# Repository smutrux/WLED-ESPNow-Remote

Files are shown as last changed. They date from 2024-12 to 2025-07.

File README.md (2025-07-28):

# WLED-ESPNow-Remote
ESPNow based remote controller for WLED using an ESP32-C3 with support for buttons, button matrix and rotary encoder. The code is Arduino based for easy compilation: developed and tested with Arduino IDE version 2.3.4

Hardware setup and button settings can be easily configured in the source code.

## Features
- Support for up to 6 standard button inputs (more when not using deep-sleep)
- Support for up to 36 buttons when using a 6x6 button matrix
- Support for rotary encoder input with configurable number of levels (see below)
- Each button can be assigned up to 3 functions: single click, double click and long press with automatic repeat
- Makes use of the low-power capabilities for battery powered remote controllers

## Supported hardware
- Controller: ESP32 C3
- Buttons: any button or sensor that has an active-low signal i.e. pulls to GND, external pullups are optional
- Button Matrix: any button matrix with row and column outputs with up to 6 rows and 6 columns, no external resistors or diodes required
- Rotary encoder: standard rotary encoders are supported, 1M external pullups are recommended for battery powered remotes

## Hardware setup
It is recommended to use the suggested pins given in the code. GPIO9 (boot pin) can generally not be used. For normal buttons, use GPIO0 through GPIO5. Any higher numbered GPIOs do not have wake-up capabilities and are only responsive when not in deep-sleep.

You can use the `ESP32_ESPNow_receiver.ino` in the `tools` folder running on a second ESP32 (should work on any ESP32 flavour) and open the serial monitor to check for received button codes. As an alternative: using a WLED device with debug output enabled will also display received messages on the serial output. 

### Standard Buttons
Connect each button between the GPIO and GND. External pull-up resistors are not needed but can be used, it makes no difference to functionality.

If more than 6 buttons are needed there are several options:
- use a matrix button configuration
- disable deep-sleep (`#DISABLE_DEEPSLEEP` in `config.h`) and any GPIO can be used (even GPIO9 although not recommended) at the expense of about **8 fold increased power consumption** (0.35mA vs. 0.04mA)
- use a button connected to GPIO0-GPIO5 to wake from deep sleep: during `ACTIVE_TIME` (see `config.h`) all configured GPIOs are responsive. Adjust `ACTIVE_TIME`  to your requriements

### Button Matrix
Connect the column-pins to GPIO0-GPIO5 as they are used as the inputs and need to be able to awaken the controller from deep-sleep. Connect the row-pins to any GPIO **except GPIO9**. Avoid pins with LEDs connected to them (GPIO8 on the C3 supermini for example) as it leads to (much) increased standby power consumption. 

The code is already set-up for a 4x4 button matrix, use the pins recommended in the code if possible. 

The button numbering is done from left to right, top to bottom with column 0 being on the left and row 0 being the top row. 

### Rotary Encoder
The CLK and DT pins of the encoder should be connected to GPIO0 and GPIO1. GPIO3, 4 and 5 can also be used, avoid any GPIOs with on-board pullups (i.e. GPIO2). 

For the button pin the use of GPIO2 is recommended although any GPIO from GPIO0 to GPIO5 can be used.

When using a rotary encoder module, connect GND to GND of the ESP and + to 3.3V of the ESP.

Additional buttons can be connected if required, the same restrictions mentioned above apply.

#### Tips for longer battery life using a rotary encoder
Standard rotary encoders have two resting postions: both (DT and CLK) pins floating and both pins connected to GND. To detect signals in deep-sleep an external pullup resistor is required. 
When using rotary encoder modules, these resistors are already in place, however, they consume a lot of power: when the two pins are in GND state, the pullup resistor of usually 10k resulting in deep-sleep curren of 700uA vs. ~45uA (see below). 

One way to get around this is to replace the resistors with higher value ones: 1M resistors work well, values larger than 3M are too weak to pull the pins to a reliable voltage. On the DT pin, an external resistor is not required and can be omitted.
Using 1M pull-up resistor only adds ~3uA per resistor to the deep-sleep current.

If you have no such resistors available, removing/omitting any pull-up resistors and enabling the `ENABLE_DEEPSLEEP_PULL` option is also possible, the internal pull-up resistors have a value of ~50k. Since only the pull-up on the CLK pin is enabled in deep-sleep,
the resulting current will be about 100uA. 

## Configuring and uploading the code
The default configuration uses 6 standard button inputs on GPIO0 - GPIO5. You can use this default configuration even when using less than 6 buttons: unused button pins will simple be idle and have no influence on power consumption. 

To upload the code, use the Arduino IDE (version 2.3.4 tested, newer version may or may not work)

Since the program puts the ESP in sleep mode, upload only works in bootloader mode: disconnect from USB, press and hold the boot button on the ESP32 C3, connect to USB then release the button and upload the code. Press reset after uploading to exit the bootloader.

By default, the on-board LED (GPIO8) will blink when data is sent out. If you see no blinking when pressing a button, there is something wrong with your hardware setup or the code was not uploaded properly. As mentioned above you can use the provided receiver sketch to for testing. 

### Changing the configuration
To change the hardware configuration, adjust the code in `config.h` according to your setup: comments in that file hopefully make it clear what each config parameter is used for.

The function numbers assigned to each button can be changed in the buttons.ino file where I added some examples. WLED supports the standard WiZ-mote codes by default, however those are highly limited in use. 
You can add a `remote.json` file to WLED using a web-browser (wled-ip/edit) to assign any supported JSON-API command to any button function. 

Triggering a preset using the command `{"ps":5}` to trigger preset 5 for example and adding the JSON-commands in the WLED web UI allows for easier adjustments than editing the remote.json file as that requires an active internet connection for the editor.

Example remote.json files are provided in the remote-json folder.

For details about the JSON-API please see [the documentation](https://kno.wled.ge)

## WLED setup
On your WLED controller you need to enable the ESPNow support and pair the remote in config->WiFi Setup, see https://kno.wled.ge/interfaces/infrared/#esp-now-based-remote-control

## How it all works
ESPNow is a wifi frequency based protocol by Espressif that works without an active wifi connection. This allows for low power communication as devices can quickly send messages without having to go 
through the wifi authentification process. The ESPNow remote code broadcasts a small message across all wifi channels (1-13) so it can be picked up by any WLED controller, no matter on what
channel it is currently on. This also works if the WLED controller is not connected to any wifi i.e. in AP mode. 

Since the messages are "blindly" broadcast there is no acknowledgement sent by the receiving controller. The remote therefore does not know if a message was received, all it knows if the message was sent: if there is heavy traffic
on the wifi channel used it can lead to messages being lost: the remote detects message collisions with normal wifi traffic and will try to send the message again but there is no guarantee that it will go through.
This can lead to messages sometimes being lost. If there is heavy traffic in your network and a lot of messages get lost, try increasing the `REPEATSEND` parameter or change the channel.

### Rotary encoder 
Standard rotary encoders allow to detect the rotation direction and trigger a message send out for each detent. To be able to control more settings, the "level" can be changed with a double-click on the encoder button.
The codes sent out for rotation are (counter clockwise / clockwise):

- level 0: WIZMOTE_BUTTON_BRIGHT_DOWN = 8 / WIZMOTE_BUTTON_BRIGHT_UP = 9
- level 1: WIZMOTE_BUTTON_ONE = 16 	  / WIZMOTE_BUTTON_ONE+1 = 17
- level 2: WIZMOTE_BUTTON_ONE+2 = 18 	  / WIZMOTE_BUTTON_ONE+3 = 19

(higher levels continue the same way)

- WIZMOTE_BUTTON_ONE+1 is also WIZMOTE_BUTTON_TWO
- WIZMOTE_BUTTON_ONE+2 is also WIZMOTE_BUTTON_THREE
- WIZMOTE_BUTTON_ONE+3 is also WIZMOTE_BUTTON_FOUR

these have default actions defined in WLED if no remote.json file is found

after some idle time (KEEPROTARYLEVEL_TIME) the level will be reset to 0 so that if you pick-up the remote after some time, it is set to the default of controlling brightness.

## Battery operation
The remote controller code was written and optimized for battery operated devices using a ESP32 C3 supermini. These controllers work down to ~3.6V input voltage on the 5V pin and are therefore perfectly suited for lithium polymer batteries. 
When the power LED is removed (see below) these controllers use only ~45uA (micro amperes or 0.045mA) when put into deep-sleep allowing for a very long battery life: a small 500mAh battery will last over a year without recharge.

Only use batteries with built-in protection circuits or use an external battery protection module for safety. It is also recommended to connect the battery through a charger module so it can be easily recharged.

Connect the battery power to the 5V and GND pin of the ESP board, using an external 3.3V regulator and using the 3.3V pin is not recommended as it increases power consumption unless the LDO on the ESP is removed. 

A key-press and the following sendout use about the same amount of enery as the remote uses in 2 minutes of deep-sleep, assuming the modifications mentioned i.e. removing the power LED. 
So unless a button is pressed more than 700 times per day, the deep-sleep power consumption is the dominating factor: hence the importance of low deep-sleep current. 

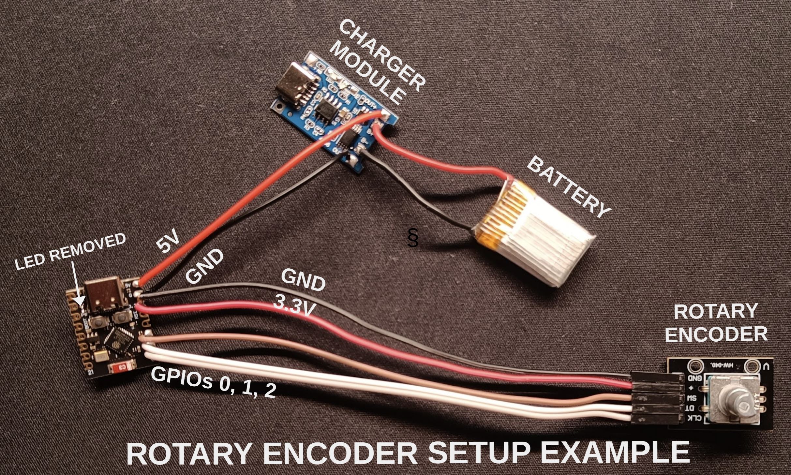
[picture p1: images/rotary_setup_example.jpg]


### Controller modifications for low power
The power-LED on the controller uses "a lot" of current, around 1mA and it is the dominating factor for battery life. It has to be removed to achieve the proclaimed ~45uA. The best (but not easiest) way to do this is to desolder it. 
It can also be cut/destroyed using pointy side-cutters or a knife, however there is the risk of damaging other components when not being careful. The small black resistor just next to the LED can also be removed as it is only used for the LED.

For more reliable operation add a 4.7uF or larger ceramic capacitor between the 3.3V pin and GND: I use 0805 sized 10uF/25V capacitors soldered directly to the C3 supermini pads. The capacitor helps to store energy required for the send-bursts.

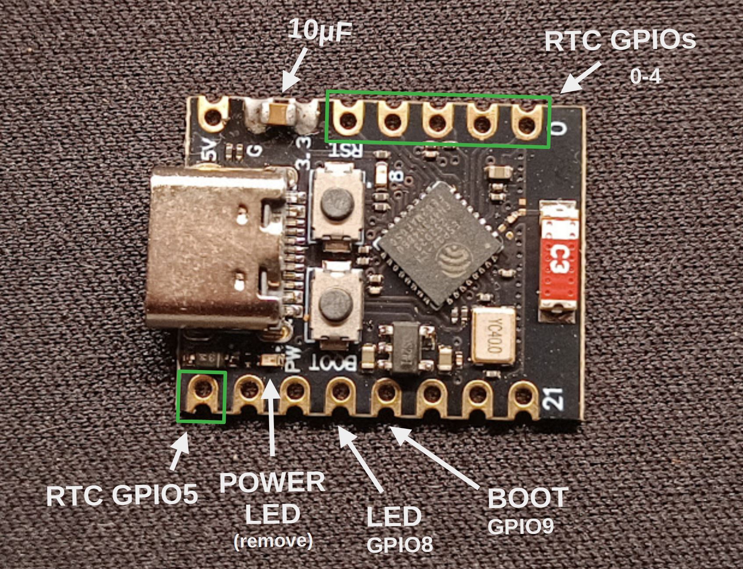
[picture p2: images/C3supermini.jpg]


### Note on ESP32 C3 Supermini variants
There are several variations of the C3 supermini, at least one of them is know to cause issues with the wifi-reception due to bad hardware design. The badly designe ones are easy to spot if you know what exactly to look for.
Here is a side-by-side comparison of the good and the bad.

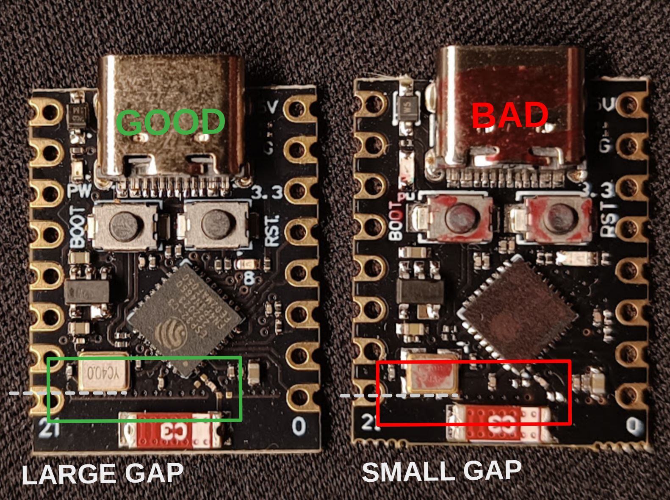
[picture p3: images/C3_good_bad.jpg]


I only own one of the bad ones and mine still works ok, the signal strength is reduced by about 50%. 

## Finished remote
PXL_20250728_000420064 RAW-01 MP COVER
PXL_20250728_000413364 RAW-01 MP COVER
PXL_20250728_000352728 RAW-01 MP COVER
PXL_20250728_000436622 RAW-01 MP COVER
PXL_20250728_000428658 RAW-01 MP COVER

## Examples for button modules
During development and testing I tried several different button-module designs that are commonly available in internet shops. Here are some fotos of tested and working configurations and which GPIOs are best to be used.

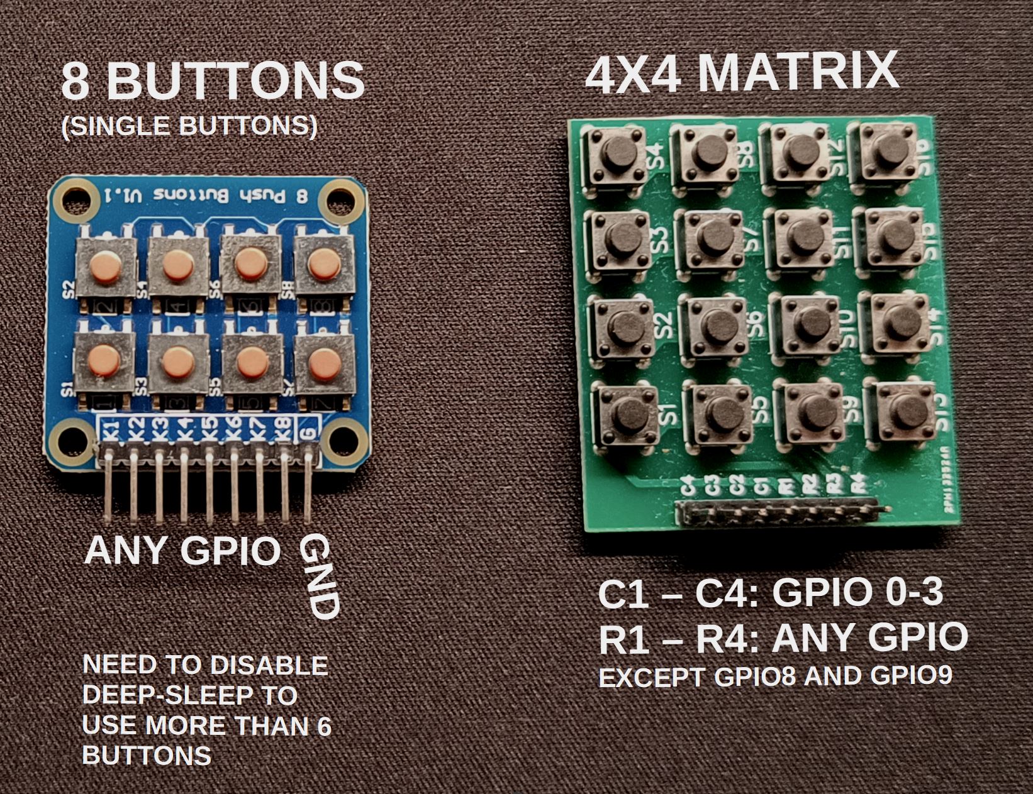
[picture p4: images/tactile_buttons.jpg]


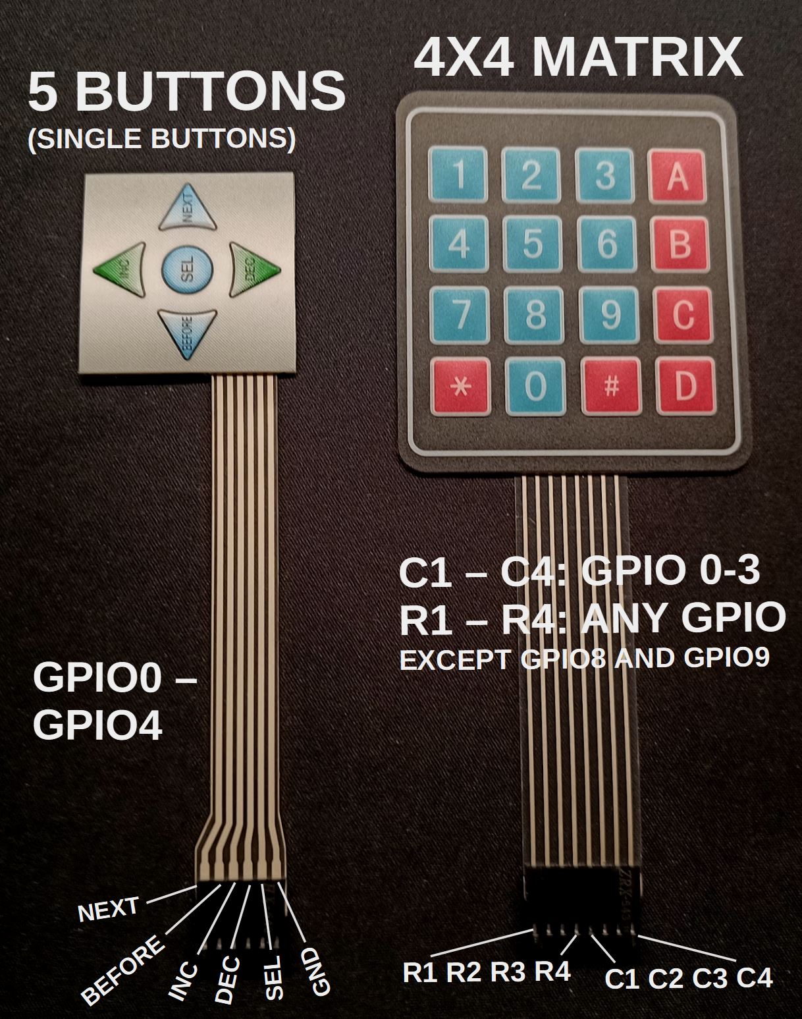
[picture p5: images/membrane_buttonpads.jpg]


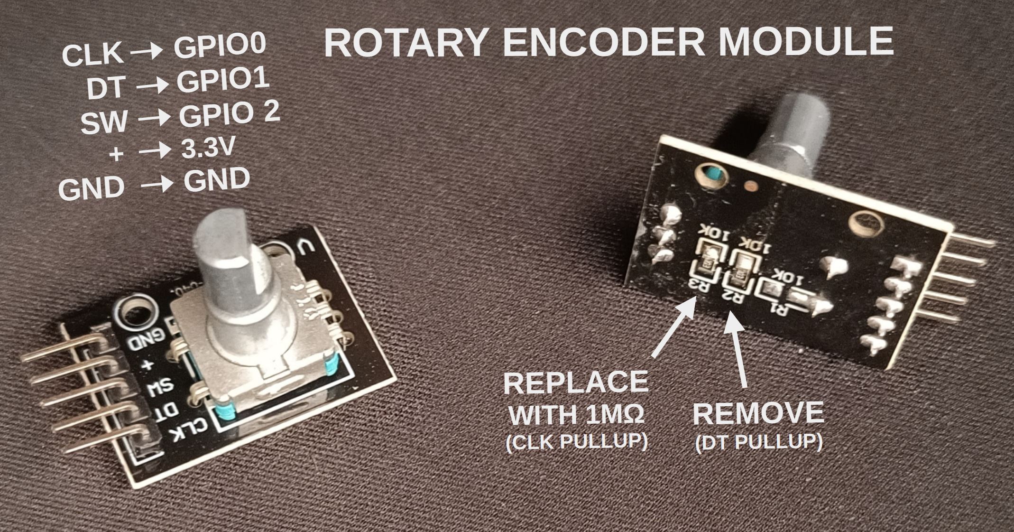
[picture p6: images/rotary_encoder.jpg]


## License and Credits

Licensed under the EUPL v1.2 license  
Code written and maintained by @DedeHai

*Disclaimer:*   

As per the EUPL license, I assume no liability for any damage to you or any other person or equipment.

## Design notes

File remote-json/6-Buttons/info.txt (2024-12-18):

Example remote.json for 6 buttons:

button0 single click: preset 1
button0 double click: preset 2
button0 long  press: preset 3

button1 single click: preset 4
button1 double click: preset 5
button1 long  press: preset 6

etc.

set DEFAULTS_START in buttons.ino to 0 and all buttons will use the default functions used in this example.
The default starts at button function number 16.
The example commands simply trigger a different preset for each button function.

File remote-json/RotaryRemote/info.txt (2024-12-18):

Example remote.json for remote with rotary encoder:

button single click: on
button double click: change level (no action sent)
button long  press: off

rotary level0 clockwise: increase brightness
rotary level0 counter-clockwise: decrease brightness

rotary level1 clockwise: next preset (presets 1 to 15)
rotary level1 counter-clockwise: previous preset (preset 1 to 15)

rotary level2 clockwise: next palette
rotary level2 counter-clockwise: previous palette

in buttons.ino:
set DEFAULTS_START to 1

use this configuration for the button:

buttons[0].singleClickFunction = WIZMOTE_BUTTON_ON; // = code 1
buttons[0].doubleClickFunction = 0;  // used to change rotary level
buttons[0].longPressFunction = WIZMOTE_BUTTON_OFF;  // = code 2
 
set NUM_ROTARYLEVELS to 3

Turning the rotary encoder will send these codes for different levels: coutnerclockwise / clockwise
- level 0: WIZMOTE_BUTTON_BRIGHT_DOWN = 8 / WIZMOTE_BUTTON_BRIGHT_UP = 9
- level 1: WIZMOTE_BUTTON_ONE = 16 	  / WIZMOTE_BUTTON_ONE+1 = 17
- level 2: WIZMOTE_BUTTON_ONE+2 = 18 	  / WIZMOTE_BUTTON_ONE+3 = 19

(higher levels continue the same way)

note:
WIZMOTE_BUTTON_ONE+1 is also WIZMOTE_BUTTON_TWO
WIZMOTE_BUTTON_ONE+2 is also WIZMOTE_BUTTON_THREE
WIZMOTE_BUTTON_ONE+3 is also WIZMOTE_BUTTON_FOUR

these have default actions defined in WLED if no remote.json file is found

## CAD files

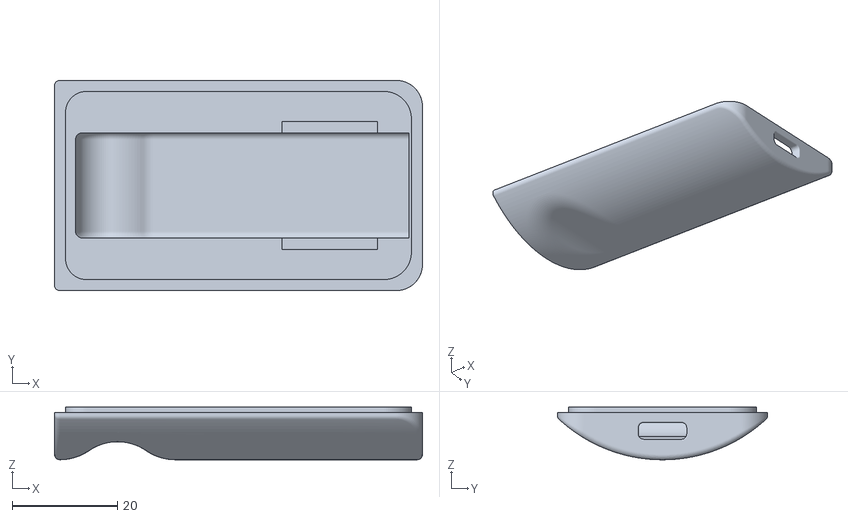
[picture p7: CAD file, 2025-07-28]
Wled Remote Shell Bottom V5.stl
70.0 x 40.0 x 10.0

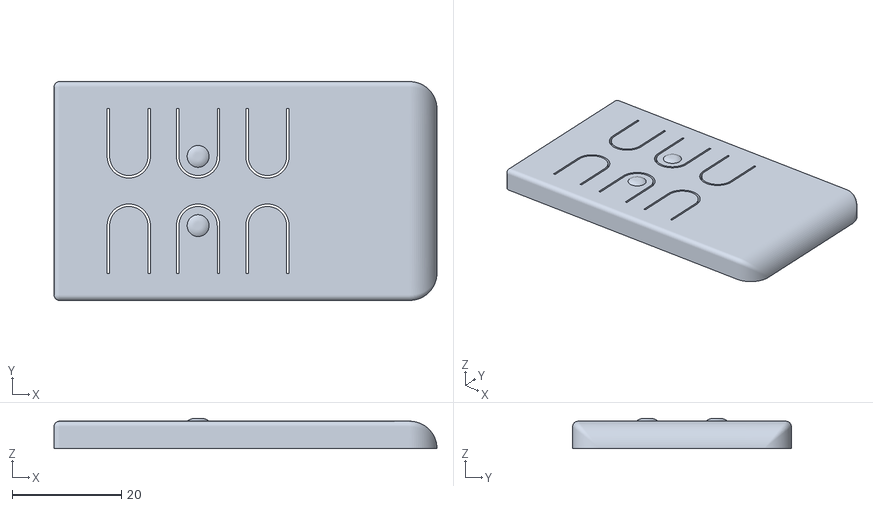
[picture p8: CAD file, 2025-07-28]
Wled Remote Shell Top V4.stl
70.0 x 40.0 x 5.50

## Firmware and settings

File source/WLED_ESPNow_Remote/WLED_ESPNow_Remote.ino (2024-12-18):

/**********************************************************************
  
  ESPNow based remote controller for WLED using ESP32 C3
  with support for buttons, button matrix and rotary encoder

  Copyright (c) 2024  Damian Schneider (@DedeHai)
  Licensed under the EUPL v. 1.2 or later
  https://github.com/DedeHai/WLED-ESPNow-Remote

  Configuration:
   - hardware settings: config.h
   - button function assignment: buttons.ino
   - more info is available in the project readme

***********************************************************************/

#include <esp_now.h>
#include <esp_wifi.h>
#include <WiFi.h>
#include "config.h"
#include "globals.h"


/////////////// SETUP /////////////////
void setup() {
  setCpuFrequencyMhz(80);  // reduce clock to minimum supported by wifi peripheral to save power
  pinMode(LED_PIN, OUTPUT);
  LED_OFF;  

  initButtons();    // initialize buttons, update states

#ifdef ROTARY_ENCODER
  if (esp_sleep_get_wakeup_cause() == ESP_SLEEP_WAKEUP_TIMER) {  // timer wakeup from deep sleep, reset rotary level and go to sleep for good
    rotaryLevel = 0;
    enterDeepSleep(0);  // calling with a time of 0 will go to sleep indefinitely
  }
  // Inputs
  pinMode(CLK_PIN, INPUT_PULLUP);
  pinMode(DT_PIN, INPUT_PULLUP);
#endif

  initEspNow();     // 45ms
  esp_wifi_stop();  // disable wifi until sendout to save power (wifi on: 23mA, wifi off: 0.3mA)

  //TODO: need to handle infinite button press gracefully, maybe go to deep sleep for 1s after a time limit of 1 minute? it will still drain the battery due to pullup but not as fast
}

/////////////// MAIN LOOP /////////////////
void loop() {
  static uint32_t lastsendtime = 0;
  uint32_t sleeptime = 1000000;  // default sleep time while active is 1s, shorter if there is messages queued or button action going on note: this could be increased but it saves little additional power, polling once per second ensures status stays correct in case of missed pulses

  uint32_t now = esp_timer_get_time();
  if (now - lastButtonEdgeTime < DOUBLE_CLICK_TIME * 1000) sleeptime = BUTTONPOLLINTERVAL;  // poll buttons if there was any changes recently
  else if (anyButtonPressed()) sleeptime = LONG_PRESS_TIME / 3 * 1000;                      // check for long press (200ms default) after double-click window has passed
  else if (!buffer_is_empty()) sleeptime = MINSENDINTERVAL;                                 // sleep for sendout interval until buffer is empty

  // monitor the inputs until an action is queued
  sleepAndMonitor(sleeptime, false);  // runs input handlers on GPIO wakeup, polls button state when waking up

  if (esp_timer_get_time() - lastsendtime > MINSENDINTERVAL) {  // too fast sending can cause trouble: overloaded clients, overloaded queue, both result in unresponsive sends, full wifi peripheral reset is possible but slow
    uint8_t command = 0;
    if (buffer_read(command)) {
       LED_ON;  
#ifdef ROTARY_ENCODER
      attachInterrupt(digitalPinToInterrupt(CLK_PIN), clk_pin_isr, CHANGE);  // enable pin interrupts during sendout
#endif
      if (command > 0) {
        sendPress(command);  // send command through ESPNow, one send takes xxx ms
        lastsendtime = esp_timer_get_time();
      }
#ifdef ROTARY_ENCODER
      detachInterrupt(digitalPinToInterrupt(CLK_PIN));  // disable pin interrupts: interrupt during sleep can causes continuous firing of ISR, even if flags are cleared manually, so use polling at wakeup
#endif
       LED_OFF;
    }
  }
#ifndef DISABLE_DEEPSLEEP // enter deep sleep if not disabled
  if (esp_timer_get_time() - lastsendtime > ACTIVE_TIME * 1000) {
#ifdef ROTARY_ENCODER
    enterDeepSleep(KEEPROTARYLEVEL_TIME * 1000000);
#else
    enterDeepSleep(0);  // go to deep sleep indefinitely
#endif
  }
#endif
}

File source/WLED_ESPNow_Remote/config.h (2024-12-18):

/**********************************************************************
  ESPNow remote for WLED
  Copyright (c) 2024  Damian Schneider (@DedeHai)
  Licensed under the EUPL v. 1.2 or later
  https://github.com/DedeHai/WLED-ESPNow-Remote
***********************************************************************/


//#define DISABLE_DEEPSLEEP // uncomment to disable going to deepsleep: any GPIO can be used for a button at the expense of ~8x shorter battery life

//hardware configuration  note: using both ROTARY_ENCODER and BUTTON_MATRIX may work but is untested
//#define ROTARY_ENCODER // uncomment to use rotary encoder (can have additional buttons)
//#define BUTTON_MATRIX  // uncomment to use a button matrix as input

/////////////////////////////
// ROTARY ENCODER SETTINGS //
/////////////////////////////
#if defined(ROTARY_ENCODER)
//#define ENABLE_DEEPSLEEP_PULL  // uncomment to use internal pullup on CLK pin during deep sleep (uses an extra 70-100uA, highly recommended to use 1M - 3M external pullup on CLK line, no pullup on DT lineand use GPIO2 for button. Internal can be used when no external resistors are available)
#define NUM_BUTTONS 1            // rotary encoder only hase one button but it is possible to add more
#define NUM_ROTARYLEVELS 3       // number of rotary levels: double click on rotary button goes to next level, sending higher numbered button codes, can be set as large as 127. Set to 1 if not using levels. DO NOT SET TO 0
#define ACTIVE_TIME 20000        // time in milliseconds to stay active (i.e. in light sleep handling inputs) before going back to deep sleep (in deep sleep, first one or two rotary positions are missed until awake, even when using wake-up stub)
#define KEEPROTARYLEVEL_TIME 40  // time in seconds until rotaryLevel is reset to 0 after ACTIVE_TIME has passed
// rotary encoder pins (can only use RTC pins, GPIO0-GPIO5), if direction is inverted, flip CLK and DT. Highly recommended to use GPIO2 for button pin as it has an on-board pullup, do not use GPIO2 for CLK or DT (increased deep sleep current)
#define CLK_PIN 0
#define DT_PIN 1
#define ROTBUTTON_PIN 2
RTC_DATA_ATTR uint8_t buttonPins[NUM_BUTTONS] = { ROTBUTTON_PIN };  // can add more buttons if needed, ROTBUTTON_PIN must be at index 0

////////////////////////////
// BUTTON MATRIX SETTINGS //
////////////////////////////
#elif defined(BUTTON_MATRIX)
#define MATRIX_COLS 4    // number of columns, connect colums to GPIO 0-5, they are used as interrupt inputs
#define MATRIX_ROWS 4    // number of rows, connect to any GPIO except GPIO9 (boot pin), if at all possible avoid pins with pullups to save power (i.e. GPIO2, GPIO8 on the C3 supermini)
#define NUM_BUTTONS (MATRIX_COLS * MATRIX_ROWS)    // change assigned function numbers in initButtons()
RTC_DATA_ATTR uint8_t columnPins[MATRIX_COLS] = { 0, 1, 2, 3 };   // column input pins, must be RTC capable pins (GPIO 0-5). These are usually marked C1, C2,... on the matrix
RTC_DATA_ATTR uint8_t rowPins[MATRIX_ROWS] = { 5, 6, 7, 10 };     // row output scanning pins, do not use GPIO9 (or it may not boot) avoid GPIO8 (LED pin). These are usually marked R1, R2,... on the matrix
#define ACTIVE_TIME 2000  // time in milliseconds to stay active (i.e. in light sleep handling inputs) before going back to deep sleep note: making this short, like 1s, can lead to missing buttons (probably while entering deep sleep)
//////////////////////////////
// STANDARD BUTTON SETTINGS //
//////////////////////////////
#else                      // normal buttons directly connected to GPIOs (external pullups are not required)
#define NUM_BUTTONS 6      // define the number of buttons and the used pins (only GPIO0-5 can be used to wake from deepsleep, if using other GPIOs, they are only detectable during ACTIVE_TIME, avoid GPIO9 = boot pin)
RTC_DATA_ATTR uint8_t buttonPins[NUM_BUTTONS] = { 0, 1, 2, 3, 4, 5 };  // GPIOs to use for buttons, change assigned function numbers in initButtons()
#define ACTIVE_TIME 6000   // time in milliseconds to stay active (i.e. in light sleep handling inputs & sendouts) before going back to deep sleep note: making this short, like 1s, can lead to missing buttons (probably while entering deep sleep)
#endif

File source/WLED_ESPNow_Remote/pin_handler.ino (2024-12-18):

/**********************************************************************
  ESPNow remote for WLED
  Copyright (c) 2024  Damian Schneider (@DedeHai)
  Licensed under the EUPL v. 1.2 or later
  https://github.com/DedeHai/WLED-ESPNow-Remote
***********************************************************************/

#define BUTTON_MINPULSE 3  // minimum time in ms between valid button state changes

// function is called when detecting rising/falling edge on button pin and periodically while button is pressed to detect long press
void IRAM_ATTR handleButtons() {
  uint8_t buttonfunction = 0;  // button function, is added to send queue if > 0
  readButtons(); // read button GPIOs, saved to currentButtonState[]
  uint32_t now = esp_timer_get_time();

  for (int i = 0; i < NUM_BUTTONS; i++) {
    uint32_t actionduration = (now - buttons[i].lastchange) / 1000;  // time in milliseconds since last state change  note: esp_timer_get_time() works with light sleep but not with deepsleep
    if (actionduration < BUTTON_MINPULSE) continue;                  // deglitch: reject short pulses
    bool buttonReleased = currentButtonState[i];                     // low is pressed, high is released

    if (buttons[i].buttonPressed)  // button was previously pressed, check for long pressed or single press if released
    {      
      if (buttonReleased == true) {
        buttons[i].buttonPressed = false;
        buttons[i].lastchange = now;
        lastButtonEdgeTime = now;
      } else if (actionduration >= LONG_PRESS_TIME) {
        buttons[i].longPress = true;
        buttons[i].buttonClicks = 0;  // reset single click
        buttons[i].lastchange = now;  // reset time (long press will repeat)
        lastButtonEdgeTime = now;
      }
    } else if (buttonReleased == false) {  // button was not pressed -> new press detected
      buttons[i].buttonPressed = true;
      buttons[i].buttonClicks++;
      buttons[i].lastchange = now;
      lastButtonEdgeTime = now;
      continue;  // wait for button to be released to determine the function to send
    } else       // button is still released
      buttons[i].buttonPressed = false;

    // now handle button action
    if (buttons[i].longPress) {
      buttons[i].longPress = false;  //reset (repeats if still pressed after another period)
      buttonfunction = buttons[i].longPressFunction;
    }

    if (buttons[i].buttonClicks > 0 && buttonReleased && actionduration >= DOUBLE_CLICK_TIME) {  // process single click after time window for double cklick has passed
      buttons[i].buttonClicks = 0;
      buttonfunction = buttons[i].singleClickFunction;
    }

    if (buttons[i].buttonClicks > 1) {  // second click detected, process it immediately (do not wait for button release), a long press still happens if button is not released
      buttons[i].buttonClicks = 0;
#ifdef ROTARY_ENCODER
      if (i == 0)                                            // rotary button has index 0
        rotaryLevel = (rotaryLevel + 1) % NUM_ROTARYLEVELS;  // go to next level on double click
#endif
      buttonfunction = buttons[i].doubleClickFunction;
    }

    if (buttonfunction > 0)
      buffer_push(buttonfunction);
    buttonfunction = 0; // reset for next pin
  }
}

#ifdef ROTARY_ENCODER
static unsigned deglitchtime;      // timestamp for non-blocking deglitching of clk-pin: glitches are rare and short, usually less than 100us
static unsigned dtState;           // for interrupt based rotary readout
#define ROTARY_DEBOUNCE_DELAY 500  // read new CLK pin state no sooner to avoid switching-glitches: time in microseconds
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

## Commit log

2024-12-25 bugfix: added explicit cast
    [ESP32_ESPNow_receiver.ino]
2024-12-25 added explicit cast to callback
    this fixes compile errors on some versions
    [ESPNow.ino]
2025-07-28 Adding 3d model
    [Wled Remote Shell Bottom V5.stl, Wled Remote Shell Top V4.stl]
